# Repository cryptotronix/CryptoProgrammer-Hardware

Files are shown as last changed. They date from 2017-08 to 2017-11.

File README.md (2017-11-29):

# Crypto Programmer Hardware

This repo is the hardware files for the Crypto Programmer, a tool that
is hopefully useful for working with the Microchip
CryptoAuthentication Line.

Microchip already makes a useful development git
(https://www.microchip.com/developmenttools/productdetails.aspx?partno=at88ck101sk-mah-xpro),
and the schematics and firmware, but we wanted to "Build our own
Birdfeeder." The intention for this project is to fully Open Source
Hardware, although it doesn't quite meet the definition:
https://www.oshwa.org/definition/

## Overview

The intention of this tool is to expose a scripting-like interface on
a USB-Host that can send the raw byte commands to the part over
I2C. In other words, it is an USB-to-I2C bridge. Most dedicated
USB-to-I2C bridge have a hard-stop of a reasonable number of
bytes. The CryptoAuthentication parts however, send commands in the
few hundred bytes in a continuous I2C frame. Hence, why this tool
exists.

The other use-case for this tool is that you could program the MCU and
then use it to program other CryptoAuthentication parts with the use
of the "extra special button." I often lift CryptoAuthentication parts
from PCBs, drop them in a socket and dump their memory and this tool
should make that easier for me as well.

## Hardware Required

You'll want to attach the USB micro cable to the Crypto Programmer
then attach the plug-side to an appropriate port. I2C lines are on the
right-angle header and you can fly-wire to your heart's content, but
your life will be much easier if you get yourself the AT88CK101 Kit
(https://www.microchip.com/developmenttools/productdetails.aspx?partno=at88ck101sk-mah-xpro)
which comes with a UDFN or SOIC8 socket. The right angle header will
mate with the socket board. This will allow you to test your code
against the Microchip tools, use the CryptoProgammer, and then attach
it to a Microchip development board like a SAMV71.

## Status

Rev A of the Hardware is done and works (we think). We are still
working on the firmware, so once that's in a workable state that will
be released under a BSD license.

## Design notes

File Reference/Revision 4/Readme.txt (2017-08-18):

Filelist:
SAML21_Xplained_Pro_layer_plots_release_rev4.pdf : PCB Layer Plots
SAML21_Xplained_Pro_design_documentation_release_rev4.pdf : Design Documentation
SAML21_Xplained_Pro_PCB_stackup_rev4.pdf : PCB stackup used in the design.
BOM\Bill of Materials Print- SAML21_Xplained_Pro_release_rev4.xls : BOM, fitted components
CAD Source\* : Altium project source files
ExportSTEP\SAML21_Xplained_Pro_release_rev4.step : 3D Model of PCBA
Gerber\SAML21_Xplained_Pro_release_rev4.GP1 : Gerber files for GND
Gerber\SAML21_Xplained_Pro_release_rev4.GP2 : Gerber files for POWER
Gerber\SAML21_Xplained_Pro_release_rev4.GM1 : Gerber files for Mechanical 1
Gerber\SAML21_Xplained_Pro_release_rev4.GBO : Gerber files for Bottom Overlay
Gerber\SAML21_Xplained_Pro_release_rev4.GBL : Gerber files for Bottom Layer LF-signals
Gerber\SAML21_Xplained_Pro_release_rev4.GBS : Gerber files for Bottom Solder
Gerber\SAML21_Xplained_Pro_release_rev4.GBP : Gerber files for Bottom Paste
Gerber\SAML21_Xplained_Pro_release_rev4.GTL : Gerber files for Top Layer LF-signals
Gerber\SAML21_Xplained_Pro_release_rev4.GTO : Gerber files for Top Overlay
Gerber\SAML21_Xplained_Pro_release_rev4.GTP : Gerber files for Top Paste
Gerber\SAML21_Xplained_Pro_release_rev4.GTS : Gerber files for Top Solder
NC Drill\SAML21_Xplained_Pro_release_rev4.drl : Drill files, gerber
NC Drill\SAML21_Xplained_Pro_release_rev4.drr : Drill Files Report
ODB\SAML21_Xplained_Pro_release_rev4.zip : ODB++ Files
Pick Place\Pick Place for SAML21_Xplained_Pro_release_rev4.txt : Pick and Place file, component placement
Test Points\Assembly Testpoint Report for SAML21_Xplained_Pro_release_rev4.txt : Assembly Testpoint report, txt
Test Points\Assembly Testpoint Report for SAML21_Xplained_Pro_release_rev4.csv : Assembly Testpoint report, csv
NC Drill\SAML21_Xplained_Pro_release_rev4.LDP : Layer Pairs Definition
NC Drill\SAML21_Xplained_Pro_-SlotHoles_release_rev4.txt : Drill files, ASCII-SlotHoles
NC Drill\SAML21_Xplained_Pro_-RoundHoles_release_rev4.txt : Drill files, ASCII-RoundHoles

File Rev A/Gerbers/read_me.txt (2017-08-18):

Simply Works Electronics, LLC
Kirill V. Belyayev
kirill@kbelyayev.com
Crypto Programmer PCB, Rev A
08/11/2017

Files included:
	gerbers.zip		A zip file of all PCB gerbers

PCB Fab Requirements:
	- 2-Layer PCB Stackup
	- 1oz Top and Bottom Copper Thickness
	- Finish: Lead Free HASL
	- Soldermask on top and bottom
	- Silkscreen on top and bottom
	- PCB Thickness: 0.062"
	- PCB Material: FR-04

Gerber File Naming Conventions
	crypto_programmer.toplayer.ger		Top Copper
	crypto_programmer.tpaste.ger		Top Paste
	crypto_programmer.topsilkscreeen.ger	Top Silkscreen
	crypto_programmer.topsoldermask.ger	Top Soldermask
	crypto_programmer.bottomlayer.ger	Bottom Copper
	crypto_programmer.bpaste.ger		Bottom Paste
	crypto_programmer.bottomsilkscreeen.ger	Bottom Silkscreen
	crypto_programmer.bottomsoldermask.ger	Bottom Soldermask
	crypto_programmer.boardoutline.ger	PCB Outline
	crypto_programmer.drills.xln		Drill File, Excellon 24 format

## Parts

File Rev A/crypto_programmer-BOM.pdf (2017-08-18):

8/18/2017 | crypto_programmer-BOM.html
file:///mnt/Windows/Users/Kirill/Documents/GitHub/Crypto-Programmer/Rev%20A/crypto_programmer-BOM.html | 1/2

Partlist exported from /home/kirill/GitHub/Crypto-Programmer/Rev A/crypto_programmer.sch at 8/18/17 10:07 AM

Qty Value | Device | Package | Parts Description | MAN-
PART_NUM | MANUFACTURER VALUE
1 | 1.0K | R-US_R0603 | R0603 | R6 | RESISTOR, American symbol
3 | 1.0uF | C-EUC0603 | C0603 | C6, C14, C15 | CAPACITOR, European symbol
2 | 10.0K | R-US_R0603 | R0603 | R5, R8 RESISTOR, American
| | | | | symbol
5 | 100nF | C-EUC0603 | C0603 | C1, C5, C9, C11, C13 | CAPACITOR, European symbol
1 | 10104111-0001LF 10104111-0001LF 10104111-
| | | 0001LF | J1 | USB - micro AB USB 2.0
Receptacle Connector | 10104111-0001LF Amphenol
2 | 10uF | C-EUC0805 | C0805 | C10, C12 | CAPACITOR, European symbol
2 | 150 | R-US_R0603 | R0603 | R3, R4 RESISTOR, American
| | | | | symbol
2 | 1825910-6 | SWITCH-TACT- TH | SWITCH-TACT-
TH | S1, S2 Standard Tactile Switch
SPST-NO Top Actuated 1825910-6 | TE Connectivity
1 | 330 | R-US_R0603 | R0603 | R7 | RESISTOR, American
| | | | | symbol
2 | 4.75K | R-US_R0603 | R0603 | R1, R2 RESISTOR, American
| | | | | symbol
1 | ATSAML21E18B-
| AU | ATSAML21E18B-
| | AU | ATSAML21E18-
| | | AU | U1 | ARM® Cortex®-M0+
| | | | | SAM L21E
| | | | | Microcontroller IC 32-Bit
| | | | | 48MHz 256KB (256K x
8) FLASH

ATSAML21E18B-
AUT | Atmel
1 | BLM18PG471SN1D L0603 | L0603 | L1 | Various Inductors
1 | DNP | ABL-8.000MHZ-
| | B2 | ABL-
8.000MHZ-B2 X1 | 8MHz ±20ppm Crystal | ABL-8.000MHZ-
| | | | | | B2 | Abracon
1 | DNP | ABS07AIG- | ABS07AIG- | X2 | 32.768kHz ±20ppm | ABS07AIG- | Abracon

8/18/2017 | crypto_programmer-BOM.html
file:///mnt/Windows/Users/Kirill/Documents/GitHub/Crypto-Programmer/Rev%20A/crypto_programmer-BOM.html | 2/2
| | 32.768KHZ-9-T 32.768KHZ-9-T | | Crystal | 32.768KHZ-9-T
5 | DNP | C-EUC0603 | C0603
| | | C2, C3, C4, C7, C8 | CAPACITOR, European symbol
1 | DNP | L0603 | L0603 | L2 | Various Inductors
3 | DNP | M20-9990246 | M20-9990246 | J4, J5,
| | | J6 | 2 Positions Header | M20-9990246 | Harwin Inc.
1 | GREEN | LTST-C190GKT 0603 | D1 | LED Indication | LTST-C190 | Lite-On Inc. | GREEN
1 | M20-9951045 | M20-9951045 | M20-9951045 | J2 | 20 Positions Header
1 | MCP1703AT- 3302E/CB | MCP1703AT- 3302E/CB MCP1703AT-
| | 3302E/CB | U2 | Linear Voltage Regulator IC | MCP1703AT- 3302E/CB | Microchip Technology
1 | RED | LTST-C190EKT 0603 | D2 | LED Indication | LTST-C190 | Lite-On Inc. | RED
1 | TC2050-IDC-NLFP TC2050-IDC-
| | NLFP TC2050-IDC-
NLFP | J3 | JTAG Cable | TC2050-IDC-
NLFP | Tag Connect

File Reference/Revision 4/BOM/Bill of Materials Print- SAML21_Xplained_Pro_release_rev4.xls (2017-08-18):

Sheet: Part List Report
 | Component list |  | Top Level Schematics
 | Source Data From: |  | SAML21_Xplained_Pro.PrjPCB
 | Project: |  | SAML21_Xplained_Pro.PrjPCB
 | Variant: |  | Default_assembly
 | Report Date: | 13.07.2015 | 13:41:57
 | Print Date: | <Parameter CurrentDate not found> | <Parameter CurrentTime not found>
Fitted | Designator | Quantity | Value | Manufacturer | MPN | Description
Fitted | BT300 | 1 | CR1220 | Panasonic | CR1220 | CR1220 Lithium coin-cell battery
Fitted | C100, C101, C104, C305, C309, C311, C701, C703 | 8 | 4.7uF | tdk | C1608X5R1A475K | Ceramic capacitor, SMD 0603, X5R, 10V, 10% (de31036)
Fitted | C102, C103, C304, C307, C308, C310, C312, C600, C602, C604, C607 | 11 | 100n | Kemet | C0402C104K4RACTU | Ceramic capacitor, SMD 0402, X7R, 16V, +/-10%
Fitted | C105, C107 | 2 | 22u/10V | tdk | C2012X5R1A226M/0.85 | Ceramic capacitor, SMD 0805, X5R, 10V, Â±20%
Fitted | C106 | 1 | 10n |  |  | Ceramic capacitor, SMD 0402, X7R, 25V, +/-10%
Fitted | C301, C302 | 2 | 6.8p |  |  | Ceramic capacitor, SMD 0402, NP0, 50V, +/-5%
Fitted | C303 | 1 | 4.7n |  |  | Ceramic capacitor, SMD 0402, X7R, 25V, +/-10% (de35287)
Fitted | C306 | 1 | 1u | Kemet | C0402C105K9PAC | Ceramic capacitor, SMD 0402, X5R, 6.3V, +/-10% (de26942)
Fitted | C400, C401 | 2 | 22p |  |  | Ceramic capacitor, SMD 0402, NP0, 50V, +/-5%
Fitted | C402 | 1 | 10p |  |  | Ceramic capacitor, SMD 0402, NP0, 50V, +/-5%
Fitted | C404, C410, C411, C412, C413 | 5 | 100n | Kemet | C0402C104K4RACTU | Ceramic capacitor, SMD 0402, X7R, 16V, +/-10%
Fitted | C405, C409, C414, C415 | 4 | 2.2uF | Kemet | C0402C225M9PAC | Ceramic capacitor, SMD 0402, X5R, 6.3V, +/-20%
Fitted | C406, C407, C408 | 3 | 1 nF C0G | Murata | GRM1555C1H102JA01D | Ceramic capacitor, SMD 0402, C0G, 50V, +/-5%
Fitted | C601, C603 | 2 | 1uF | Murata | GRM188R61E105K | Ceramic capacitor, SMD 0603, X5R, 25V, ±10%
Fitted | C605 | 1 | 33n | Murata | GRM155R71E333KA88D | Ceramic capacitor, SMD 0402, X7R, 25V, ±10%
Fitted | C606 | 1 | 1n |  |  | Ceramic capacitor, SMD 0402, X7R, 50V, +/-10%
Fitted | C700, C704 | 2 | 100nF |  |  | Ceramic capacitor, SMD 0402, High Density Footprint
Fitted | C702, C706 | 2 | 150p |  |  | Ceramic capacitor, SMD 0402, X7R, 50V, +/-10%
Fitted | D200, D402 | 2 | PRTR5V0U2X | Philips | PRTR5V0U2X | Double rail-to-rail USB ESD protection diode
Fitted | D301, D401 | 2 | EL17-21UYC/A2 | Everlight | 17-21UYC/S530-A3/TR8 | LED, Yellow, Wave length=591nm, SMD 0805, ±70°
Fitted | D400 | 1 | EL17-21SYGC | Everlight | EL17-21SYGC | LED, Green, Wave length=575nm, SMD 0805, ±70°
Fitted | E1, E2, E3, E4 | 4 | SJ-5076 | 3M | SJ-5076 | 2.8mm adhesive feet,diam 8.0mm
Fitted | FIXTURE1 | 1 | Xplained PRO MCU board Jupiter Test Fixture | ESCATEC | Xplained PRO MCU board Jupiter Test Fixture | Xplained PRO MCU board Jupiter Test Fixture
Fitted | FW1 | 1 | EDBG secured firmware | ATMEL |  | EDBG secured firmware
Fitted | J101, J102, J301 | 3 | HMTSW-103-23-F-S-237 | SAMTEC | HMTSW-103-23-F-S-237 | 1x3 pin header, 2.54mm pitch, Pin-in-Paste THM, 1mm hole
Fitted | J103 | 1 | Pin header 1x2 right angle | Pro-data International Corp | 2213R-2G | 1x2 pin header, right angle, 2.54 mm pitch, through-hole
Fitted | J200, J201, J203 | 3 | P101-2*10RGF-139-ND |  | P101-2*10RGF-139-ND | Pin header, 2x10, Right Angle, 2.54mm, THM, Pin In Paste
Fitted | J202 | 1 | P101-2*02RGF-139-ND |  | P101-2*02RGF-139-ND | Pin header, 2x2, Right Angle, 2.54mm, THT, Pin In Paste
Fitted | J204, J400 | 2 | ZX62D-AB-5P8 |  |  | Micro USB AB Connector, Standard SMT + DIP
Fitted | J205 | 1 | PIN HEADER 2x5 | Garry | STL21-0730 G TT-10U | 2x5 pin header, 1.27mm pitch, THM
Fitted | J303 | 1 | 3000TR | Keystone Corp. | 3000TR | CR1220 Li-Ion coin-cell battery clip, SMD
Fitted | J304 | 1 | HMTSW-102-23-F-S-237 | SAMTEC | HMTSW-102-23-F-S-237 | 1x2 pin header, 2.54mm pitch, Pin-in-Paste THM
Fitted | JS100, JS101, JS102, JS301, JS302 | 5 | SNT-100-BK-G | SAMTEC | SNT-100-BK-G | Jumper cap for 2.54mm pinheader
Fitted | L300 | 1 | LQH3NPN100MJ0 | Murata | LQH3NPN100MJ0 | 10uH power inductor, Isat = 560mA , Itemp = 710mA, Rdc = 0.360ohm
Fitted | L301, L401, L402, L600 | 4 | BLM18PG471SN1 | Murata | BLM18PG471SN1 | SMD RF inductor 0603. Z=470Ohm (@100MHz), Max R(dc)=0.65Ohm, Max current=1A
Fitted | L700, L701 | 2 | BLM15BB221SN1 | Murata | BLM15BB221SN1 | SMD RF inductor 0402. Z=220Ohm (@100MHz), Max R(dc)=0.80Ohm, Max current=200mA
Fitted | LABEL1 | 1 | Label PCBA | ACT Logimark AS | 505462 | PCBA identification label PP Top White Gloss
Fitted | PCB1 | 1 | SAM L21 Xplained Pro PCB |  |  | SAM L21 Xplained Pro PCB, 4 layer, 60mm x 100mm
Fitted | PCBADOC1 | 1 | A09-2241 PCBA Files |  |  | SAM L21 Xplained Pro PCBA documentation
Fitted | Q100, Q101 | 2 | IRLML6402PBF | International Rectifier | IRLML6402PBF | P-ch. MOSFET. -30V, -3.7A continuous,RDS(ON)=0.05Ohm@VGS=-4,5V, RDS(ON)=0.08Ohm@VGS=-2.5V
Fitted | Q102 | 1 | 2N7002,215 | NXP | 2N7002,215 | N-Channel MOSFET. 60V, 0.300A continuous, 1.2A Peak. RDS(ON) = 3.8Ohm@VGS=4.5V, VGS(th)<2.5V
Fitted | Q400 | 1 | 2N7002DW | Fairchild | 2N7002DW | Dual N-Channel MOSFET, 60V, 115mA cont,RDS(ON) < 7.5 Ohm @50mA@5V, SOT-363
Fitted | Q500 | 1 | PMV48XP | NXP | PMV48XP,215 | P-Channel Digital FET. -30V, -3.5A continuous, -14A Peak. RDS(ON)=48mOhm@VGS=-4.5V, RDS(ON)=71mOhm@VGS=-2.5V. VGS(th)<1.25V
Fitted | Q501, Q701 | 2 | BSS138N | Infineon | BSS138N | Low leakage N-Channel MOSFET. 60V, 0.23A continuous, 0.92A Peak. RDS(ON) = 3.5Ohm@VGS=4.5V, VGS(th)<1.4V
Fitted | Q502, Q800, Q801, Q802 | 4 | BSH201 | NXP | BSH201,215 | P-Channel Digital FET. -60V, -0.3A continuous, -1.2A Peak. RDS(ON)=2.5@VGS=-10V, RDS(ON)=<5 ohm @VGS=-2.5V. VGS(th)<1.9V
Fitted | Q700 | 1 | IRLML6402 | International Rectifier | IRLML6402PBF | P-ch. MOSFET. -30V, -3.7A continuous,RDS(ON)=0.05Ohm@VGS=-4,5V, RDS(ON)=0.08Ohm@VGS=-2.5V
Fitted | R100, R103, R104, R410, R413 | 5 | 1M |  |  | Thick film resistor, SMD 0402, 1/16W, 1%
Fitted | R101, R107, R108, R304, R500, R501, R701, R800, R801, R802 | 10 | 100k |  |  | Thick film resistor, SMD 0402, 1/16W, 1%
Fitted | R102, R606 | 2 | 39k |  |  | Thick film resistor, SMD 0402, 1/16W, 1%
Fitted | R105 | 1 | 390R |  |  | Thick film resistor, SMD 0402, 1/16W, 1%
Fitted | R106, R109, R110, R201, R805 | 5 | 47k |  |  | Thick film resistor, SMD 0402, 1/16W, 1%
Fitted | R200 | 1 | 30k |  |  | Thick film resistor, SMD 0402, 1/16W, 1%
Fitted | R203, R303, R411, R412 | 4 | 330R |  |  | Thick film resistor, SMD 0402, 1/16W, 1%
Fitted | R300, R305, R311, R421, R422, R803 | 6 | 39R |  |  | Thick film resistor, SMD 0402, 1/16W, 1%
Fitted | R301, R307, R600, R601, R706 | 5 | 0R | (n/a) | RMCF0402ZT0R00 | RES 0.0 OHM 1/16W 0402 SMD
Fitted | R302, R703, R708, R709 | 4 | 10k | vishay | CRCW040210K0FKED | Thick film resistor, SMD 0402, 1/16W, 1%
Fitted | R306, R310, R602, R603 | 4 | 4.7k |  |  | Thick film resistor, SMD 0402, 1/16W, 1%
Fitted | R401, R402, R409 | 3 | 1k |  |  | Thick film resistor, SMD 0402, 1/16W, 1%
Fitted | R414, R416, R417, R418, R419, R420 | 6 | 330R |  |  | Thick film resistor, SMD 0402, 1/16W, 1%
Fitted | R423 | 1 | 6.81k |  |  | Thick film resistor, SMD 0402, 1/16W, 1%
Fitted | R604 | 1 | 2k |  |  | Thick film resistor, SMD 0402, 1/16W, 1%
Fitted | R605 | 1 | 33k |  |  | Thick film resistor, SMD 0402, 1/16W, 1%
Fitted | R700 | 1 | 0.1R | vishay | WSL0603R1000FEA | WSL0603R1000FEA, metal strip resistor, 0.1 Ohm, +-1%, 0603 SMD, 1/10 W, TEMPCO +-75 ppm/Â°C
Fitted | R702, R704 | 2 | 100R | Panasonic | ERA3YEB101V | ERA-3YEB101V, metal film, 100R Â±0.1%, resistor in 0603 at 100mW, TEMPCO Â±25ppm/Â°C, Max V=75V
Fitted | R705 | 1 | 680R |  |  | Thick film resistor, SMD 0402, 1/16W, 1%
Fitted | R707 | 1 | 2k |  |  | Thick film resistor, SMD 0603, 1/10W, 1%
Fitted | R804 | 1 | 2.2k |  |  | Thick film resistor, SMD 0402, 1/16W, 1%
Fitted | R806 | 1 | 4.7M |  |  | Thick film SMD 0402 1/16W 1%
Fitted | SW300, SW301 | 2 | SKRAAKE010 | ALPS | SKRAAKE010 | 6.2x6.2 mm SMD tact switch, same as A08-0091 but less force is needed
Fitted | TEST1 | 1 | SAM L21 Xplained Pro Test |  |  | Fixture eggTest for SAM L21 Xplained Pro
Fitted | TESTDOC1 | 1 | SAM L21 Xplained Pro Test Instructions |  |  | SAM L21 Xplained Pro Test Instructions
Fitted | U100 | 1 | TLV70033DSE | Texas Instruments | TLV70033DSE | LDO, 200 mA, Iq=31 uA, Vdo=250mV, Vout=3.3V, VIN= 2 V to 5.5V, SON-6 package
Fitted | U101 | 1 | TPS2113PWR | Texas Instruments | TPS2113PWR | Autoswitching 2:1 Power Mux
Fitted | U102 | 1 | STMPS2161STR |  |  | Single channel power switch, 1A, reverse block, active low enabled.
Fitted | U103 | 1 | TPS73533DRV | Texas Instruments | TPS73533DRV | Low noise LDO, 500 mA, Vout=3.3V, 2% accuracy, IQ=46uA, noise=28uVrms, VIN= 2.7V to 6.5V, Vdo=280mV,stable with low ESR capacitor
Fitted | U300 | 1 | ATSAML21J18B-AUT |  |  | Atmel 32-bit RISC MCU 64pin
Fitted | U400 | 1 | AT32UC3A4256J-C1UR | ATMEL | AT32UC3A4256J-C1UR | AVR 32-bit RISC MCU
Fitted | U600 | 1 | SAMD20E17A-AUT | ATMEL | ATSAMD20E17A-AUT | Atmel 32bit RISC MCU 32 pin
Fitted | U601 | 1 | LM4041CEM3-ADJ | National Semiconductor | LM4041CEM3-ADJ | Adjustable shunt voltage regulator, 1.24 to 10V out
Fitted | U700 | 1 | AD8656 | Analog Devices | AD8656ARMZ | AD8656, dual low noise precision OpAmp, rail-to-rail, low offset 250uV, GBP 28 MHz, 8MSOP
Fitted | U701 | 1 | ADA4528-1 | Analog Devices | ADA4528-1ARMZ | Precision OpAmp, Zero-Drift 0.015uV/K, ultra low noise 5.6nV/sqrt(Hz), Vo=2uV, GBW=4MHz, single supply 2.2V to 5.5V or dual supply +-1V to +-2.75V, rail to rail, unity gain stable
Fitted | XC300 | 1 | 32.768kHz +/-20PPM 7pF SMD | Micro Crystal | MS1V-T1K 32.768kHz 7pF +/-20PPM TA | 32k768 crystal, +-20ppm, CL=7pF, max ESR 60kOhm, SMD
Fitted | XC400 | 1 | 12.0MHz | Fox Electronics | FQ5032B-12-C-C-C-200-1 | Fox FQ5032B 12.0MHz SMD crystal 738B-12
Not Fitted | C200, C403 | 0 | 4.7n |  |  | Ceramic capacitor, SMD 0402, X7R, 25V, +/-10%
Not Fitted | C300, C313 | 0 | 22p |  |  | Ceramic capacitor, SMD 0402, NP0, 50V, +/-5%
Not Fitted | C705 | 0 | 1n |  |  | Ceramic capacitor, SMD 0402, X7R, 50V, +/-10%
Not Fitted | R202, R424 | 0 | 1M | KOA | RK73H1ETTP1004F | Thick film resistor, SMD 0402, 1/16W, 1%
Not Fitted | XC301 | 0 | 12.0MHz | Fox Electronics | FQ5032B-12-C-C-C-200-1 / 738B-12 | Fox FQ5032B 12.0MHz SMD crystal 738B-12
 |  | 183
Approved |  |  | Notes

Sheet: Project Information
Project Full Path | E:\svn\devkits\SAML21_Xplained_Pro\02_Documentation\Release_Files\Atmel-42405-SAML21-Xplained-Pro_User-Guide\Revision 4\CAD Source\SAML21_Xplained_Pro.PrjPCB
Project Filename | SAML21_Xplained_Pro.PrjPCB
Variant Name | Default_assembly
Data-Source Filename | SAML21_Xplained_Pro.PrjPCB
Data-Source Full Path | E:\svn\devkits\SAML21_Xplained_Pro\02_Documentation\Release_Files\Atmel-42405-SAML21-Xplained-Pro_User-Guide\Revision 4\CAD Source\SAML21_Xplained_Pro.PrjPCB
Title | Top Level Schematics
Total Quantity | 183
Report Time | 13:41:57
Report Date | 13.07.2015
Report Date & Tine | 13.07.2015 13:41:57
Output Name | Bill of Materials Fitted
Output Type | BOM_PartType
Output Generator Name | BOM
Output Generator Description | Bill of Materials

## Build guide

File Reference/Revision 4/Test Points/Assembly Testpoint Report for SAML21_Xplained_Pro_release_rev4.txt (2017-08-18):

Net         Name        X Coord     Y Coord     Side        Hole Size   Type        
TARGET_USB_SHIELDJ204-8       -46.209mm      -4.8mm  Bottom          0.65mm  Through hole
VCC_MCU_VDDIOJ304-2       -37.055mm    -66.55mm  Bottom             1mm  Through hole
VCC_EXT_P5V0J202-1         -6.97mm    -13.49mm  Bottom             1mm  Through hole
VCC_P5V0    J202-3         -6.97mm    -16.03mm  Bottom             1mm  Through hole
VCC_TARGET_P3V3J202-4         -4.43mm    -16.03mm  Bottom             1mm  Through hole
ID2         J201-1         -6.97mm    -64.29mm  Bottom             1mm  Through hole
PA18_S1_UART_TXJ201-14        -4.43mm    -79.53mm  Bottom             1mm  Through hole
PA19_S1_UART_RXJ201-13        -6.97mm    -79.53mm  Bottom             1mm  Through hole
EDBG_SPI_DGI_MOSIJ201-16        -4.43mm    -82.07mm  Bottom             1mm  Through hole
PA17_GPIO   J201-15        -6.97mm    -82.07mm  Bottom             1mm  Through hole
EDBG_SPI_DGI_SCKJ201-18        -4.43mm    -84.61mm  Bottom             1mm  Through hole
PB16_S5_SPI_MISOJ201-17        -6.97mm    -84.61mm  Bottom             1mm  Through hole
PB14_GPIO_IRQ14J201-9         -6.97mm    -74.45mm  Bottom             1mm  Through hole
PB12_PWM_TC4_0J201-7         -6.97mm    -71.91mm  Bottom             1mm  Through hole
PB13_PWM_TC4_1J201-8         -4.43mm    -71.91mm  Bottom             1mm  Through hole
PA20_GPIO   J201-5         -6.97mm    -69.37mm  Bottom             1mm  Through hole
PA21_GPIO   J201-6         -4.43mm    -69.37mm  Bottom             1mm  Through hole
PA10_ADC18_PTCY8J201-3         -6.97mm    -66.83mm  Bottom             1mm  Through hole
PA11_ADC19  J201-4         -4.43mm    -66.83mm  Bottom             1mm  Through hole
PB15_GPIO_SSJ201-10        -4.43mm    -74.45mm  Bottom             1mm  Through hole
NetJ102_2   J103-2        -38.73mm    -10.95mm  Bottom             1mm  Through hole
VCC_MCU_P3V3J103-1        -41.27mm    -10.95mm  Bottom             1mm  Through hole
TARGET_RESETJ205-10        -8.24mm    -23.01mm  Bottom          0.65mm  Through hole
SWDIO       J205-2         -3.16mm    -23.01mm  Bottom          0.65mm  Through hole
SWDCLK      J205-4         -4.43mm    -23.01mm  Bottom          0.65mm  Through hole
ID1         J200-1         -6.97mm    -28.73mm  Bottom             1mm  Through hole
EDBG_DGI_SDAJ200-11        -6.97mm    -41.43mm  Bottom             1mm  Through hole
EDBG_DGI_SCLJ200-12        -4.43mm    -41.43mm  Bottom             1mm  Through hole
PB08_S4_UART_TXJ200-14        -4.43mm    -43.97mm  Bottom             1mm  Through hole
PB09_S4_UART_RXJ200-13        -6.97mm    -43.97mm  Bottom             1mm  Through hole
PA06_S0_SPI_MOSIJ200-16        -4.43mm    -46.51mm  Bottom             1mm  Through hole
PA05_S0_SPI_SSJ200-15        -6.97mm    -46.51mm  Bottom             1mm  Through hole
PA07_S0_SPI_SCKJ200-18        -4.43mm    -49.05mm  Bottom             1mm  Through hole
PA04_S0_SPI_MISOJ200-17        -6.97mm    -49.05mm  Bottom             1mm  Through hole
PB04_GPIO_IRQ4J200-9         -6.97mm    -38.89mm  Bottom             1mm  Through hole
PA12_PWM_TCC2_0J200-7         -6.97mm    -36.35mm  Bottom             1mm  Through hole
PA13_PWM_TCC2_1J200-8         -4.43mm    -36.35mm  Bottom             1mm  Through hole
PB06_GPIO   J200-5         -6.97mm    -33.81mm  Bottom             1mm  Through hole
PB07_GPIO   J200-6         -4.43mm    -33.81mm  Bottom             1mm  Through hole
PB05_ADC13  J200-3         -6.97mm    -31.27mm  Bottom             1mm  Through hole
PA03_ADC1   J200-4         -4.43mm    -31.27mm  Bottom             1mm  Through hole
PA02_GPIO_SS_BTNJ200-10        -4.43mm    -38.89mm  Bottom             1mm  Through hole
SHIELD      J400-9       -17.825mm      -4.8mm  Bottom          0.65mm  Through hole
PA27_GPIO_SSJ203-10       -28.73mm    -95.57mm  Bottom             1mm  Through hole
PB01_ADC9   J203-4        -21.11mm    -95.57mm  Bottom             1mm  Through hole
PB00_ADC8   J203-3        -21.11mm    -93.03mm  Bottom             1mm  Through hole
PA15_GPIO   J203-6        -23.65mm    -95.57mm  Bottom             1mm  Through hole
PB30_GPIO   J203-5        -23.65mm    -93.03mm  Bottom             1mm  Through hole
PB11_PWM_TCC0_5J203-8        -26.19mm    -95.57mm  Bottom             1mm  Through hole
PB10_PWM_TCC0_4J203-7        -26.19mm    -93.03mm  Bottom             1mm  Through hole
PA16_GPIO_IRQJ203-9        -28.73mm    -93.03mm  Bottom             1mm  Through hole
PB17_S5_SPI_SSJ203-15       -36.35mm    -93.03mm  Bottom             1mm  Through hole
ID3         J203-1        -18.57mm    -93.03mm  Bottom             1mm  Through hole
PB02_USB_ID Free-0       -33.495mm   -47.125mm  Bottom          0.65mm  Through hole
EDBG_SPI_DGI_SSFree-0       -32.225mm   -47.125mm  Bottom          0.65mm  Through hole
PA14_USB_VBUSFree-0       -36.035mm   -47.125mm  Bottom          0.65mm  Through hole
PA23_S3_UART_RXFree-0        -25.85mm   -37.275mm  Bottom          0.65mm  Through hole
EDBG_CDC_USART_RXFree-0        -27.12mm   -37.275mm  Bottom          0.65mm  Through hole
PB03_VBAT   J301-2      -47.1564mm   -51.861mm  Bottom             1mm  Through hole
VCC_BATT    J301-1      -47.1564mm   -49.321mm  Bottom             1mm  Through hole
NetJ101_3   J102-3       -41.776mm    -14.76mm  Bottom             1mm  Through hole
VCC_P3V3_CM_INJ102-1       -41.776mm    -19.84mm  Bottom             1mm  Through hole
NetR300_1   TP300-1          -33mm      -1.5mm  Bottom             0mm  Surface mount
VCC_CM_P3V3 TP407-1        -38.6mm      -7.5mm  Bottom             0mm  Surface mount
VCC_P3V3    J100-2         -27.9mm    -12.15mm  Bottom             0mm  Surface mount
NetR311_1   TP301-1          -26mm      -1.5mm  Bottom             0mm  Surface mount
GND         TP400-1        -41.6mm      -1.5mm  Bottom             0mm  Surface mount
EDBG_FORCE_BOOTTP401-1        -38.6mm      -1.5mm  Bottom             0mm  Surface mount
EDBG_JTAG_TCKTP402-1        -41.6mm      -3.5mm  Bottom             0mm  Surface mount
EDBG_JTAG_TDITP403-1        -41.6mm      -5.5mm  Bottom             0mm  Surface mount
EDBG_JTAG_TDOTP404-1        -38.6mm      -5.5mm  Bottom             0mm  Surface mount
EDBG_JTAG_TMSTP405-1        -41.6mm      -7.5mm  Bottom             0mm  Surface mount
EDBG_RESET_NTP406-1        -38.6mm      -3.5mm  Bottom             0mm  Surface mount
PA31_SWDIO  Free-3        -24.05mm  -40.0875mm  Bottom             0mm  Surface mount
PA30_SWDCLK Free-3       -23.175mm   -41.275mm  Bottom             0mm  Surface mount
NetQ700_2   Free-3        -46.85mm     -15.4mm  Bottom             0mm  Surface mount
CM_PA27_EXTINT15Free-3         -40.1mm   -28.875mm  Bottom             0mm  Surface mount
CM_PA28_EXTINT8Free-3         -40.1mm    -30.15mm  Bottom             0mm  Surface mount
NetC106_2   Free-3        -30.15mm     -7.75mm  Bottom             0mm  Surface mount
VCC_PRE_AMP_P5V0Free-3       -58.075mm    -17.65mm  Bottom             0mm  Surface mount
EDBG_SPI_DGI_MISOFree-3       -30.775mm   -26.175mm  Bottom             0mm  Surface mount
NetC706_1   Free-3       -57.425mm   -23.575mm  Bottom             0mm  Surface mount
VREF_FB     Free-3       -44.735mm     -42.8mm  Bottom             0mm  Surface mount
CM_PA15_GPIOFree-3      -50.6488mm  -28.3738mm  Bottom             0mm  Surface mount
NetQ701_3   Free-3        -51.45mm     -20.8mm  Bottom             0mm  Surface mount
VCC_CM_VDDANAFree-3         -53.7mm    -37.15mm  Bottom             0mm  Surface mount
CM_PA03_VREFAFree-3       -48.875mm    -40.45mm  Bottom             0mm  Surface mount
VCC_CM_CORE Free-3       -37.925mm     -33.1mm  Bottom             0mm  Surface mount
VCC_FILTER_P3V3Free-3       -52.625mm   -21.725mm  Bottom             0mm  Surface mount
NetC705_2   Free-3       -58.525mm    -26.95mm  Bottom             0mm  Surface mount
CM_PA08_AIN16Free-3       -52.975mm     -30.9mm  Bottom             0mm  Surface mount
NetC702_1   Free-3       -54.925mm     -32.7mm  Bottom             0mm  Surface mount
NetQ102_1   Free-3      -10.4822mm  -17.3834mm  Bottom             0mm  Surface mount
NetR100_1   Free-3       -19.825mm        -4mm  Bottom             0mm  Surface mount
VCC_EDBG_USB_P5V0Free-3        -19.85mm     -5.55mm  Bottom             0mm  Surface mount
NetQ101_1   Free-3         -15.9mm   -13.775mm  Bottom             0mm  Surface mount
NetQ500_2   Free-3       -48.125mm   -15.425mm  Bottom             0mm  Surface mount
NetQ701_1   Free-3         -52.6mm     -19.3mm  Bottom             0mm  Surface mount
NetQ701_2   Free-3       -58.225mm   -21.125mm  Bottom             0mm  Surface mount
NetQ501_3   Free-3        -50.75mm    -11.85mm  Bottom             0mm  Surface mount
NetC402_1   Free-3         -18.9mm    -19.65mm  Bottom             0mm  Surface mount
NetC405_1   Free-3       -25.575mm     -14.1mm  Bottom             0mm  Surface mount
NetQ400_6   Free-3          -4.1mm   -12.025mm  Bottom             0mm  Surface mount
NetQ400_3   Free-3        -2.575mm     -6.55mm  Bottom             0mm  Surface mount
NetR107_2   Free-3       -21.175mm    -14.55mm  Bottom             0mm  Surface mount
NetQ800_3   Free-3       -43.225mm   -22.875mm  Bottom             0mm  Surface mount
NetQ801_3   Free-3       -46.775mm   -22.875mm  Bottom             0mm  Surface mount
NetQ802_3   Free-3       -50.325mm   -22.875mm  Bottom             0mm  Surface mount
NetR105_2   Free-3        -14.15mm    -8.975mm  Bottom             0mm  Surface mount
CM_PA01_GPIOVia          -40.175mm   -26.675mm  Bottom          0.25mm  Through hole
CM_PA00_GPIOVia          -43.725mm   -26.675mm  Bottom          0.25mm  Through hole
CM_PA17_SERCOM1_SCLVia          -36.275mm    -24.95mm  Bottom          0.25mm  Through hole
CM_PA16_SERCOM1_SDAVia           -36.95mm   -23.775mm  Bottom          0.25mm  Through hole
CM_PA24_SERCOM3_PAD2_SPI_MISOVia          -20.225mm     -32.7mm  Bottom          0.25mm  Through hole
CM_PA25_SPI_SSVia           -22.55mm     -31.6mm  Bottom          0.25mm  Through hole
CM_RESET_N  Via           -25.75mm   -32.175mm  Bottom          0.25mm  Through hole
CM_PA23_SERCOM3_PAD1_SPI_SCKVia          -22.125mm     -33.4mm  Bottom          0.25mm  Through hole
CM_PA22_SERCOM3_PAD0_SPI_MOSIVia           -20.35mm    -34.05mm  Bottom          0.25mm  Through hole
CM_PA14_GCLK0Via           -21.35mm    -35.05mm  Bottom          0.25mm  Through hole
CM_PA05_AIN5Via           -52.85mm   -28.725mm  Bottom          0.25mm  Through hole
CM_PA11_GCLK5Via          -29.625mm   -25.325mm  Bottom          0.25mm  Through hole
VCC_VSW     Via          -29.075mm   -49.725mm  Bottom          0.25mm  Through hole
VCC_MCU_VDDCOREVia           -27.35mm   -49.775mm  Bottom          0.25mm  Through hole
STATUS_LED_CTRLVia             -2.7mm    -12.25mm  Bottom          0.25mm  Through hole
TARGET_USB_IDVia          -32.275mm     -15.2mm  Bottom          0.25mm  Through hole
CM_PA31_SWDIOVia          -24.675mm   -35.675mm  Bottom          0.25mm  Through hole
CM_PA30_SWCLKVia            -25.9mm   -35.125mm  Bottom          0.25mm  Through hole
TARGET_MCU_RESETVia         -28.9125mm   -27.525mm  Bottom          0.25mm  Through hole
NetCS300_1  Via           -48.75mm   -80.075mm  Bottom          0.25mm  Through hole
VCC_MCU_VDDANAVia          -40.725mm    -57.95mm  Bottom          0.25mm  Through hole
INPUT_VOLTAGE_DETECTEDVia           -9.925mm      -9.2mm  Bottom          0.25mm  Through hole
VCC_TARGET_USB_P5V0Via          -22.525mm     -11.4mm  Bottom          0.25mm  Through hole
NetD301_2   Via          -36.625mm    -11.45mm  Bottom          0.25mm  Through hole
CM_PA10_GPIOVia            -52.7mm    -32.65mm  Bottom          0.25mm  Through hole
CM_PA18_CMP0Via            -44.2mm   -20.225mm  Bottom          0.25mm  Through hole
NetQ502_3   Via           -50.75mm     -14.3mm  Bottom          0.25mm  Through hole
DGI_GPIO3   Via            -15.6mm     -26.2mm  Bottom          0.25mm  Through hole
EDBG_CDC_USART_TXVia          -27.575mm   -26.175mm  Bottom          0.25mm  Through hole
DGI_GPIO2   Via          -16.875mm     -26.2mm  Bottom          0.25mm  Through hole
DGI_GPIO1   Via           -18.15mm     -26.2mm  Bottom          0.25mm  Through hole
DGI_GPIO0   Via          -19.425mm     -26.2mm  Bottom          0.25mm  Through hole
NetD401_1   Via             -1.3mm     -7.25mm  Bottom          0.25mm  Through hole
POWER_LED_CTRLVia            -6.35mm     -8.75mm  Bottom          0.25mm  Through hole
NetD400_1   Via            -6.35mm    -10.05mm  Bottom          0.25mm  Through hole
NetC404_1   Via           -29.85mm    -20.25mm  Bottom          0.25mm  Through hole
NetC407_1   Via          -13.275mm      -7.4mm  Bottom          0.25mm  Through hole
CM_PA09_AIN17Via           -38.75mm     -22.7mm  Bottom          0.25mm  Through hole

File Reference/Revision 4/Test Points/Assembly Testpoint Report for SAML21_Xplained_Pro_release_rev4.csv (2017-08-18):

Net | Name | X Coord | Y Coord | Side | Hole Size | Type
TARGET_USB_SHIELD | J204-8 | -46.209mm | -4.8mm | Bottom | 0.65mm | Through hole
VCC_MCU_VDDIO | J304-2 | -37.055mm | -66.55mm | Bottom | 1mm | Through hole
VCC_EXT_P5V0 | J202-1 | -6.97mm | -13.49mm | Bottom | 1mm | Through hole
VCC_P5V0 | J202-3 | -6.97mm | -16.03mm | Bottom | 1mm | Through hole
VCC_TARGET_P3V3 | J202-4 | -4.43mm | -16.03mm | Bottom | 1mm | Through hole
ID2 | J201-1 | -6.97mm | -64.29mm | Bottom | 1mm | Through hole
PA18_S1_UART_TX | J201-14 | -4.43mm | -79.53mm | Bottom | 1mm | Through hole
PA19_S1_UART_RX | J201-13 | -6.97mm | -79.53mm | Bottom | 1mm | Through hole
EDBG_SPI_DGI_MOSI | J201-16 | -4.43mm | -82.07mm | Bottom | 1mm | Through hole
PA17_GPIO | J201-15 | -6.97mm | -82.07mm | Bottom | 1mm | Through hole
EDBG_SPI_DGI_SCK | J201-18 | -4.43mm | -84.61mm | Bottom | 1mm | Through hole
PB16_S5_SPI_MISO | J201-17 | -6.97mm | -84.61mm | Bottom | 1mm | Through hole
PB14_GPIO_IRQ14 | J201-9 | -6.97mm | -74.45mm | Bottom | 1mm | Through hole
PB12_PWM_TC4_0 | J201-7 | -6.97mm | -71.91mm | Bottom | 1mm | Through hole
PB13_PWM_TC4_1 | J201-8 | -4.43mm | -71.91mm | Bottom | 1mm | Through hole
PA20_GPIO | J201-5 | -6.97mm | -69.37mm | Bottom | 1mm | Through hole
PA21_GPIO | J201-6 | -4.43mm | -69.37mm | Bottom | 1mm | Through hole
PA10_ADC18_PTCY8 | J201-3 | -6.97mm | -66.83mm | Bottom | 1mm | Through hole
PA11_ADC19 | J201-4 | -4.43mm | -66.83mm | Bottom | 1mm | Through hole
PB15_GPIO_SS | J201-10 | -4.43mm | -74.45mm | Bottom | 1mm | Through hole
NetJ102_2 | J103-2 | -38.73mm | -10.95mm | Bottom | 1mm | Through hole
VCC_MCU_P3V3 | J103-1 | -41.27mm | -10.95mm | Bottom | 1mm | Through hole
TARGET_RESET | J205-10 | -8.24mm | -23.01mm | Bottom | 0.65mm | Through hole
SWDIO | J205-2 | -3.16mm | -23.01mm | Bottom | 0.65mm | Through hole
SWDCLK | J205-4 | -4.43mm | -23.01mm | Bottom | 0.65mm | Through hole
ID1 | J200-1 | -6.97mm | -28.73mm | Bottom | 1mm | Through hole
EDBG_DGI_SDA | J200-11 | -6.97mm | -41.43mm | Bottom | 1mm | Through hole
EDBG_DGI_SCL | J200-12 | -4.43mm | -41.43mm | Bottom | 1mm | Through hole
PB08_S4_UART_TX | J200-14 | -4.43mm | -43.97mm | Bottom | 1mm | Through hole
PB09_S4_UART_RX | J200-13 | -6.97mm | -43.97mm | Bottom | 1mm | Through hole
PA06_S0_SPI_MOSI | J200-16 | -4.43mm | -46.51mm | Bottom | 1mm | Through hole
PA05_S0_SPI_SS | J200-15 | -6.97mm | -46.51mm | Bottom | 1mm | Through hole
PA07_S0_SPI_SCK | J200-18 | -4.43mm | -49.05mm | Bottom | 1mm | Through hole
PA04_S0_SPI_MISO | J200-17 | -6.97mm | -49.05mm | Bottom | 1mm | Through hole
PB04_GPIO_IRQ4 | J200-9 | -6.97mm | -38.89mm | Bottom | 1mm | Through hole
PA12_PWM_TCC2_0 | J200-7 | -6.97mm | -36.35mm | Bottom | 1mm | Through hole
PA13_PWM_TCC2_1 | J200-8 | -4.43mm | -36.35mm | Bottom | 1mm | Through hole
PB06_GPIO | J200-5 | -6.97mm | -33.81mm | Bottom | 1mm | Through hole
PB07_GPIO | J200-6 | -4.43mm | -33.81mm | Bottom | 1mm | Through hole
PB05_ADC13 | J200-3 | -6.97mm | -31.27mm | Bottom | 1mm | Through hole
PA03_ADC1 | J200-4 | -4.43mm | -31.27mm | Bottom | 1mm | Through hole
PA02_GPIO_SS_BTN | J200-10 | -4.43mm | -38.89mm | Bottom | 1mm | Through hole
SHIELD | J400-9 | -17.825mm | -4.8mm | Bottom | 0.65mm | Through hole
PA27_GPIO_SS | J203-10 | -28.73mm | -95.57mm | Bottom | 1mm | Through hole
PB01_ADC9 | J203-4 | -21.11mm | -95.57mm | Bottom | 1mm | Through hole
PB00_ADC8 | J203-3 | -21.11mm | -93.03mm | Bottom | 1mm | Through hole
PA15_GPIO | J203-6 | -23.65mm | -95.57mm | Bottom | 1mm | Through hole
PB30_GPIO | J203-5 | -23.65mm | -93.03mm | Bottom | 1mm | Through hole
PB11_PWM_TCC0_5 | J203-8 | -26.19mm | -95.57mm | Bottom | 1mm | Through hole
PB10_PWM_TCC0_4 | J203-7 | -26.19mm | -93.03mm | Bottom | 1mm | Through hole
PA16_GPIO_IRQ | J203-9 | -28.73mm | -93.03mm | Bottom | 1mm | Through hole
PB17_S5_SPI_SS | J203-15 | -36.35mm | -93.03mm | Bottom | 1mm | Through hole
ID3 | J203-1 | -18.57mm | -93.03mm | Bottom | 1mm | Through hole
PB02_USB_ID | Free-0 | -33.495mm | -47.125mm | Bottom | 0.65mm | Through hole
EDBG_SPI_DGI_SS | Free-0 | -32.225mm | -47.125mm | Bottom | 0.65mm | Through hole
PA14_USB_VBUS | Free-0 | -36.035mm | -47.125mm | Bottom | 0.65mm | Through hole
PA23_S3_UART_RX | Free-0 | -25.85mm | -37.275mm | Bottom | 0.65mm | Through hole
EDBG_CDC_USART_RX | Free-0 | -27.12mm | -37.275mm | Bottom | 0.65mm | Through hole
PB03_VBAT | J301-2 | -47.1564mm | -51.861mm | Bottom | 1mm | Through hole
VCC_BATT | J301-1 | -47.1564mm | -49.321mm | Bottom | 1mm | Through hole
NetJ101_3 | J102-3 | -41.776mm | -14.76mm | Bottom | 1mm | Through hole
VCC_P3V3_CM_IN | J102-1 | -41.776mm | -19.84mm | Bottom | 1mm | Through hole
NetR300_1 | TP300-1 | -33mm | -1.5mm | Bottom | 0mm | Surface mount
VCC_CM_P3V3 | TP407-1 | -38.6mm | -7.5mm | Bottom | 0mm | Surface mount
VCC_P3V3 | J100-2 | -27.9mm | -12.15mm | Bottom | 0mm | Surface mount
NetR311_1 | TP301-1 | -26mm | -1.5mm | Bottom | 0mm | Surface mount
GND | TP400-1 | -41.6mm | -1.5mm | Bottom | 0mm | Surface mount
EDBG_FORCE_BOOT | TP401-1 | -38.6mm | -1.5mm | Bottom | 0mm | Surface mount
EDBG_JTAG_TCK | TP402-1 | -41.6mm | -3.5mm | Bottom | 0mm | Surface mount
EDBG_JTAG_TDI | TP403-1 | -41.6mm | -5.5mm | Bottom | 0mm | Surface mount
EDBG_JTAG_TDO | TP404-1 | -38.6mm | -5.5mm | Bottom | 0mm | Surface mount
EDBG_JTAG_TMS | TP405-1 | -41.6mm | -7.5mm | Bottom | 0mm | Surface mount
EDBG_RESET_N | TP406-1 | -38.6mm | -3.5mm | Bottom | 0mm | Surface mount
PA31_SWDIO | Free-3 | -24.05mm | -40.0875mm | Bottom | 0mm | Surface mount
PA30_SWDCLK | Free-3 | -23.175mm | -41.275mm | Bottom | 0mm | Surface mount
NetQ700_2 | Free-3 | -46.85mm | -15.4mm | Bottom | 0mm | Surface mount
CM_PA27_EXTINT15 | Free-3 | -40.1mm | -28.875mm | Bottom | 0mm | Surface mount
CM_PA28_EXTINT8 | Free-3 | -40.1mm | -30.15mm | Bottom | 0mm | Surface mount
NetC106_2 | Free-3 | -30.15mm | -7.75mm | Bottom | 0mm | Surface mount
VCC_PRE_AMP_P5V0 | Free-3 | -58.075mm | -17.65mm | Bottom | 0mm | Surface mount
EDBG_SPI_DGI_MISO | Free-3 | -30.775mm | -26.175mm | Bottom | 0mm | Surface mount
NetC706_1 | Free-3 | -57.425mm | -23.575mm | Bottom | 0mm | Surface mount
VREF_FB | Free-3 | -44.735mm | -42.8mm | Bottom | 0mm | Surface mount
CM_PA15_GPIO | Free-3 | -50.6488mm | -28.3738mm | Bottom | 0mm | Surface mount
NetQ701_3 | Free-3 | -51.45mm | -20.8mm | Bottom | 0mm | Surface mount
VCC_CM_VDDANA | Free-3 | -53.7mm | -37.15mm | Bottom | 0mm | Surface mount
CM_PA03_VREFA | Free-3 | -48.875mm | -40.45mm | Bottom | 0mm | Surface mount
VCC_CM_CORE | Free-3 | -37.925mm | -33.1mm | Bottom | 0mm | Surface mount
VCC_FILTER_P3V3 | Free-3 | -52.625mm | -21.725mm | Bottom | 0mm | Surface mount
NetC705_2 | Free-3 | -58.525mm | -26.95mm | Bottom | 0mm | Surface mount
CM_PA08_AIN16 | Free-3 | -52.975mm | -30.9mm | Bottom | 0mm | Surface mount
NetC702_1 | Free-3 | -54.925mm | -32.7mm | Bottom | 0mm | Surface mount
NetQ102_1 | Free-3 | -10.4822mm | -17.3834mm | Bottom | 0mm | Surface mount
NetR100_1 | Free-3 | -19.825mm | -4mm | Bottom | 0mm | Surface mount
VCC_EDBG_USB_P5V0 | Free-3 | -19.85mm | -5.55mm | Bottom | 0mm | Surface mount
NetQ101_1 | Free-3 | -15.9mm | -13.775mm | Bottom | 0mm | Surface mount
NetQ500_2 | Free-3 | -48.125mm | -15.425mm | Bottom | 0mm | Surface mount
NetQ701_1 | Free-3 | -52.6mm | -19.3mm | Bottom | 0mm | Surface mount
NetQ701_2 | Free-3 | -58.225mm | -21.125mm | Bottom | 0mm | Surface mount
NetQ501_3 | Free-3 | -50.75mm | -11.85mm | Bottom | 0mm | Surface mount
NetC402_1 | Free-3 | -18.9mm | -19.65mm | Bottom | 0mm | Surface mount
NetC405_1 | Free-3 | -25.575mm | -14.1mm | Bottom | 0mm | Surface mount
NetQ400_6 | Free-3 | -4.1mm | -12.025mm | Bottom | 0mm | Surface mount
NetQ400_3 | Free-3 | -2.575mm | -6.55mm | Bottom | 0mm | Surface mount
NetR107_2 | Free-3 | -21.175mm | -14.55mm | Bottom | 0mm | Surface mount
NetQ800_3 | Free-3 | -43.225mm | -22.875mm | Bottom | 0mm | Surface mount
NetQ801_3 | Free-3 | -46.775mm | -22.875mm | Bottom | 0mm | Surface mount
NetQ802_3 | Free-3 | -50.325mm | -22.875mm | Bottom | 0mm | Surface mount
NetR105_2 | Free-3 | -14.15mm | -8.975mm | Bottom | 0mm | Surface mount
CM_PA01_GPIO | Via | -40.175mm | -26.675mm | Bottom | 0.25mm | Through hole
CM_PA00_GPIO | Via | -43.725mm | -26.675mm | Bottom | 0.25mm | Through hole
CM_PA17_SERCOM1_SCL | Via | -36.275mm | -24.95mm | Bottom | 0.25mm | Through hole
CM_PA16_SERCOM1_SDA | Via | -36.95mm | -23.775mm | Bottom | 0.25mm | Through hole
CM_PA24_SERCOM3_PAD2_SPI_MISO | Via | -20.225mm | -32.7mm | Bottom | 0.25mm | Through hole
CM_PA25_SPI_SS | Via | -22.55mm | -31.6mm | Bottom | 0.25mm | Through hole
CM_RESET_N | Via | -25.75mm | -32.175mm | Bottom | 0.25mm | Through hole
CM_PA23_SERCOM3_PAD1_SPI_SCK | Via | -22.125mm | -33.4mm | Bottom | 0.25mm | Through hole
CM_PA22_SERCOM3_PAD0_SPI_MOSI | Via | -20.35mm | -34.05mm | Bottom | 0.25mm | Through hole
CM_PA14_GCLK0 | Via | -21.35mm | -35.05mm | Bottom | 0.25mm | Through hole
CM_PA05_AIN5 | Via | -52.85mm | -28.725mm | Bottom | 0.25mm | Through hole
CM_PA11_GCLK5 | Via | -29.625mm | -25.325mm | Bottom | 0.25mm | Through hole
VCC_VSW | Via | -29.075mm | -49.725mm | Bottom | 0.25mm | Through hole
VCC_MCU_VDDCORE | Via | -27.35mm | -49.775mm | Bottom | 0.25mm | Through hole
STATUS_LED_CTRL | Via | -2.7mm | -12.25mm | Bottom | 0.25mm | Through hole
TARGET_USB_ID | Via | -32.275mm | -15.2mm | Bottom | 0.25mm | Through hole
CM_PA31_SWDIO | Via | -24.675mm | -35.675mm | Bottom | 0.25mm | Through hole
CM_PA30_SWCLK | Via | -25.9mm | -35.125mm | Bottom | 0.25mm | Through hole
TARGET_MCU_RESET | Via | -28.9125mm | -27.525mm | Bottom | 0.25mm | Through hole
NetCS300_1 | Via | -48.75mm | -80.075mm | Bottom | 0.25mm | Through hole
VCC_MCU_VDDANA | Via | -40.725mm | -57.95mm | Bottom | 0.25mm | Through hole
INPUT_VOLTAGE_DETECTED | Via | -9.925mm | -9.2mm | Bottom | 0.25mm | Through hole
VCC_TARGET_USB_P5V0 | Via | -22.525mm | -11.4mm | Bottom | 0.25mm | Through hole
NetD301_2 | Via | -36.625mm | -11.45mm | Bottom | 0.25mm | Through hole
CM_PA10_GPIO | Via | -52.7mm | -32.65mm | Bottom | 0.25mm | Through hole
CM_PA18_CMP0 | Via | -44.2mm | -20.225mm | Bottom | 0.25mm | Through hole
NetQ502_3 | Via | -50.75mm | -14.3mm | Bottom | 0.25mm | Through hole
DGI_GPIO3 | Via | -15.6mm | -26.2mm | Bottom | 0.25mm | Through hole
EDBG_CDC_USART_TX | Via | -27.575mm | -26.175mm | Bottom | 0.25mm | Through hole
DGI_GPIO2 | Via | -16.875mm | -26.2mm | Bottom | 0.25mm | Through hole
DGI_GPIO1 | Via | -18.15mm | -26.2mm | Bottom | 0.25mm | Through hole
DGI_GPIO0 | Via | -19.425mm | -26.2mm | Bottom | 0.25mm | Through hole
NetD401_1 | Via | -1.3mm | -7.25mm | Bottom | 0.25mm | Through hole
POWER_LED_CTRL | Via | -6.35mm | -8.75mm | Bottom | 0.25mm | Through hole
NetD400_1 | Via | -6.35mm | -10.05mm | Bottom | 0.25mm | Through hole
NetC404_1 | Via | -29.85mm | -20.25mm | Bottom | 0.25mm | Through hole
NetC407_1 | Via | -13.275mm | -7.4mm | Bottom | 0.25mm | Through hole
CM_PA09_AIN17 | Via | -38.75mm | -22.7mm | Bottom | 0.25mm | Through hole

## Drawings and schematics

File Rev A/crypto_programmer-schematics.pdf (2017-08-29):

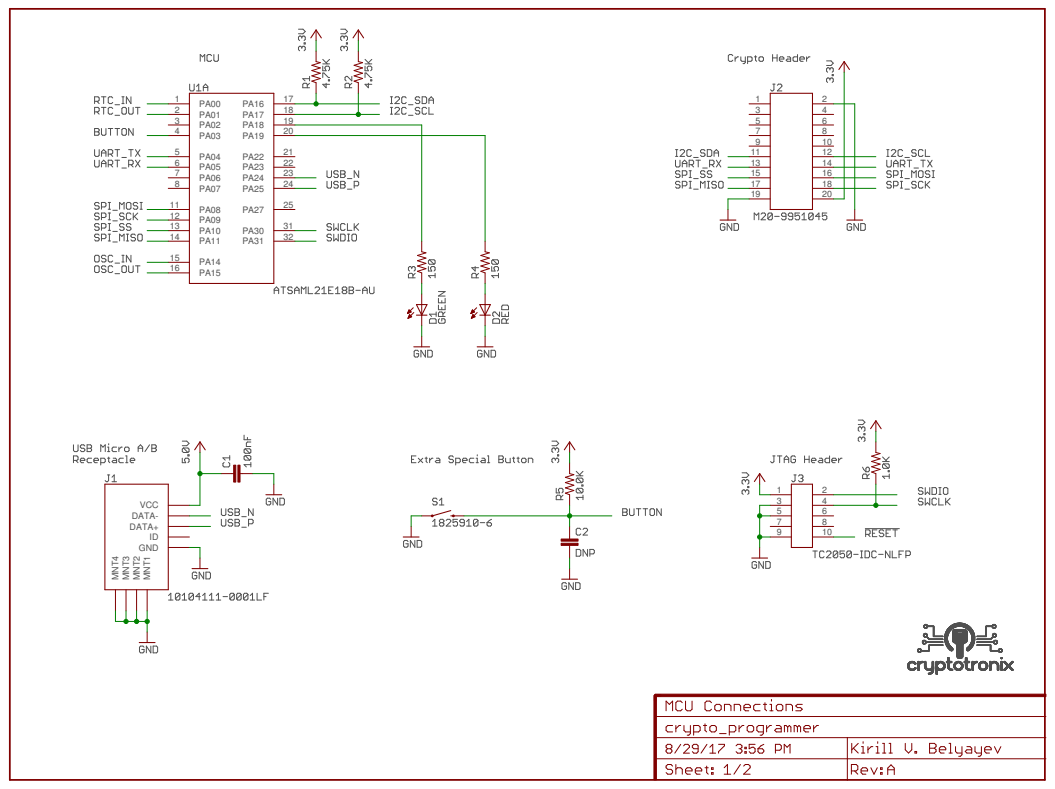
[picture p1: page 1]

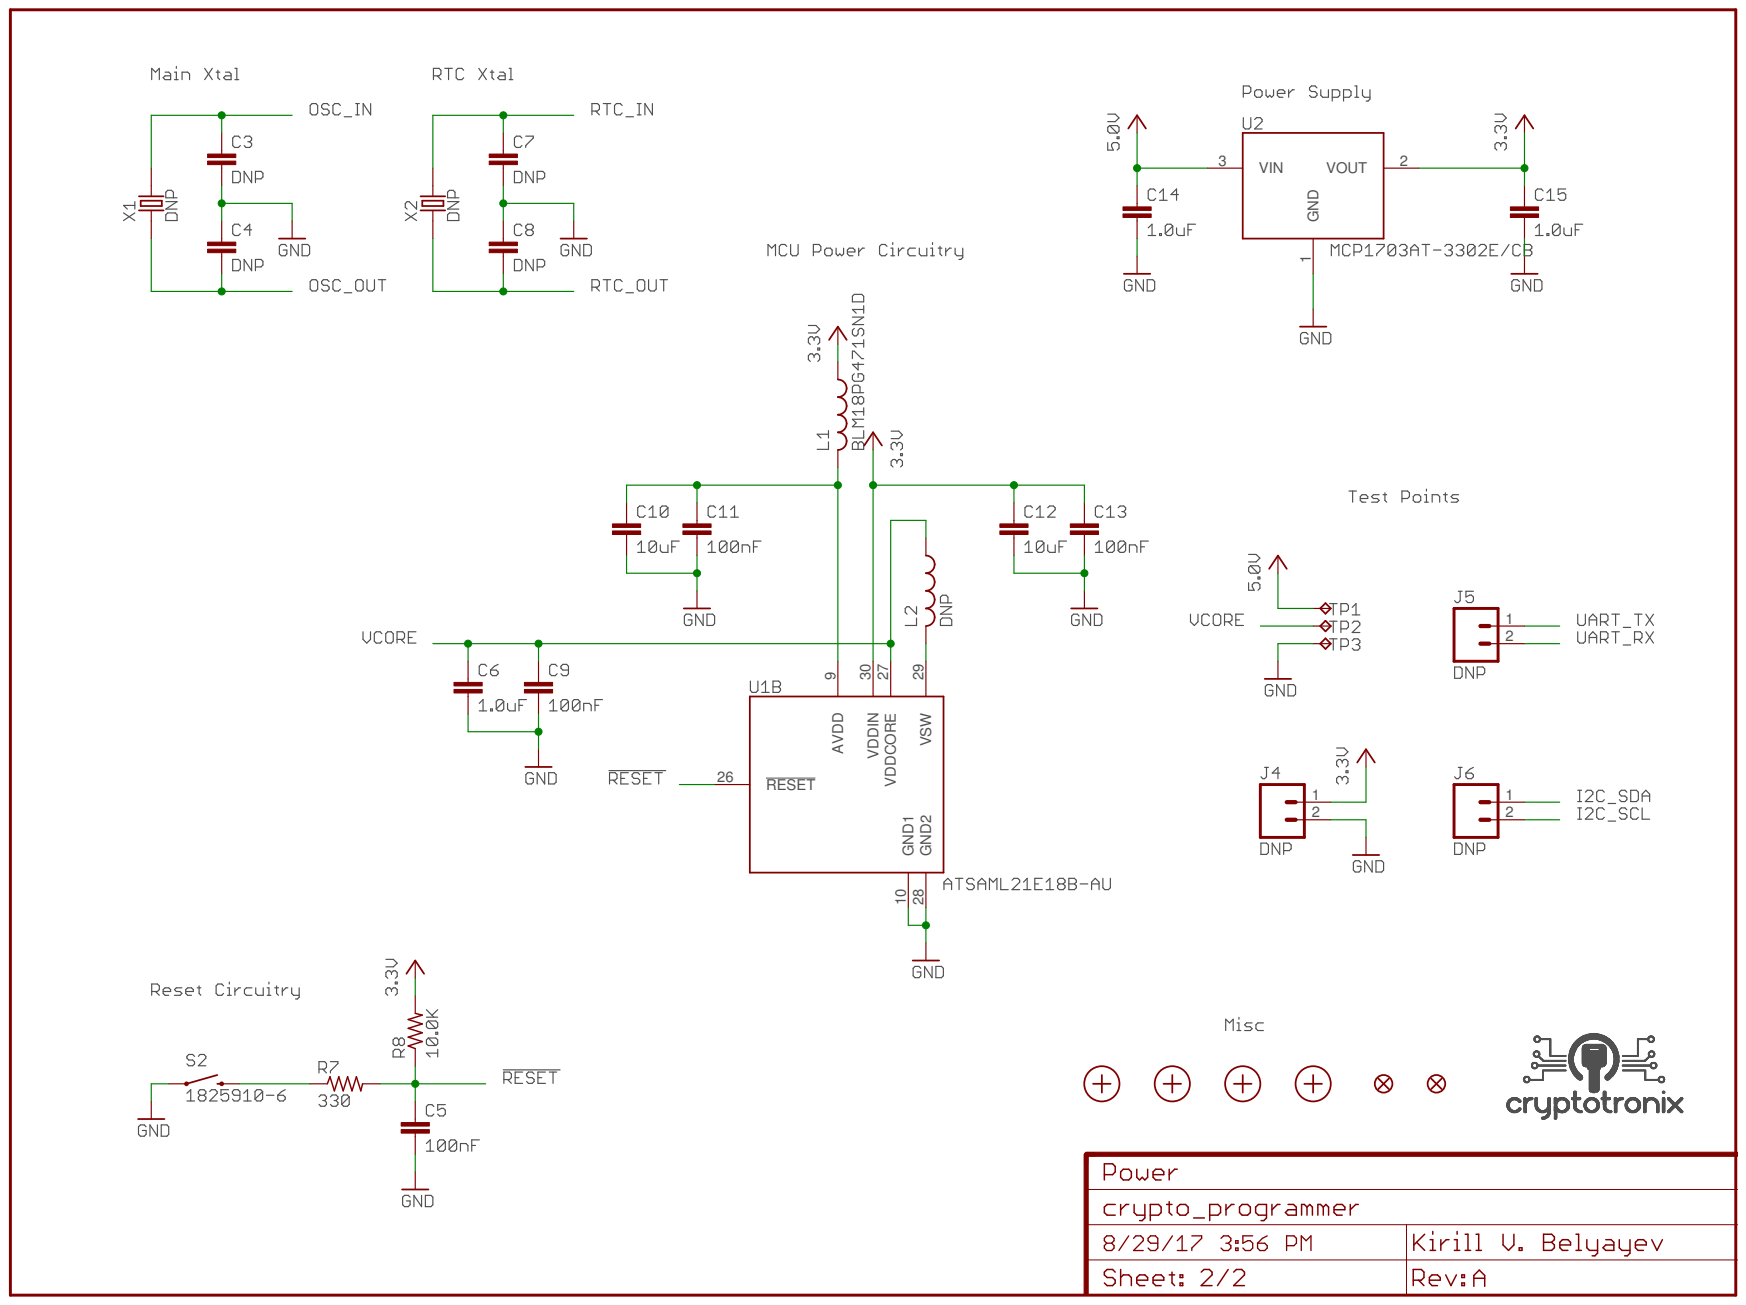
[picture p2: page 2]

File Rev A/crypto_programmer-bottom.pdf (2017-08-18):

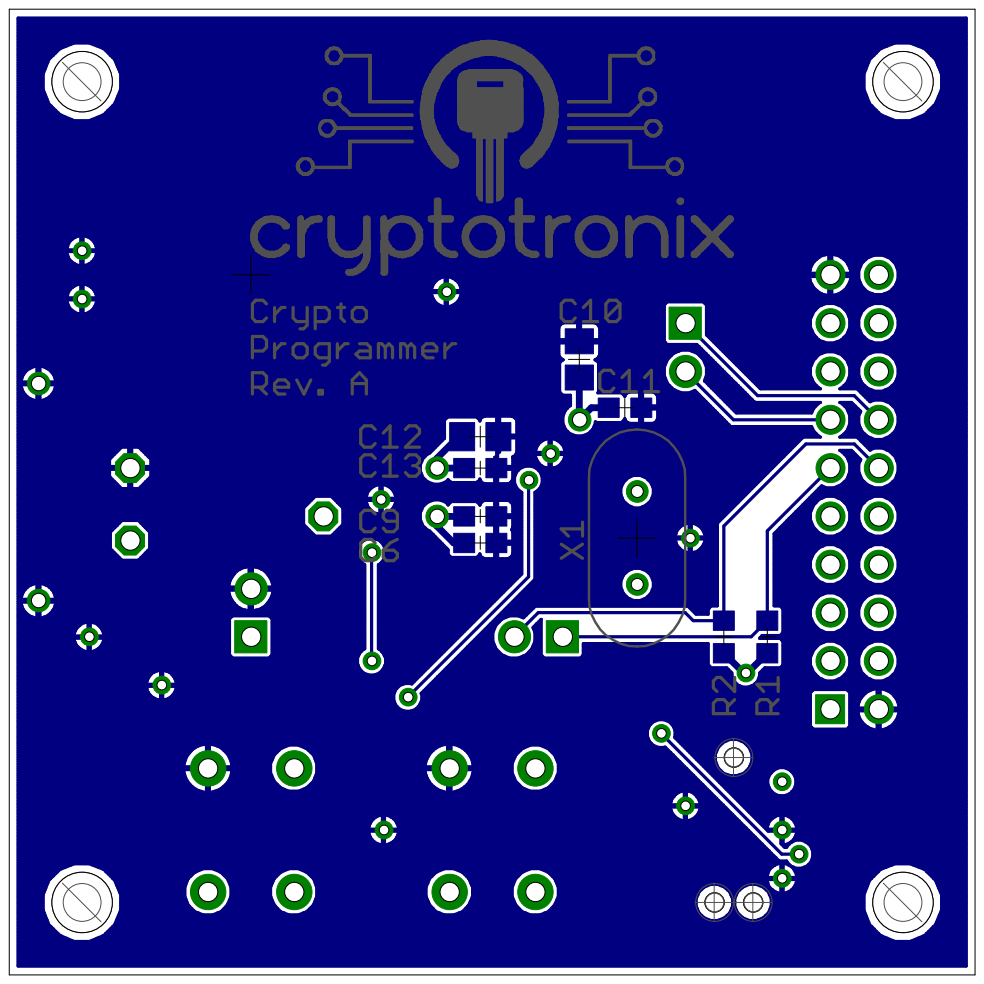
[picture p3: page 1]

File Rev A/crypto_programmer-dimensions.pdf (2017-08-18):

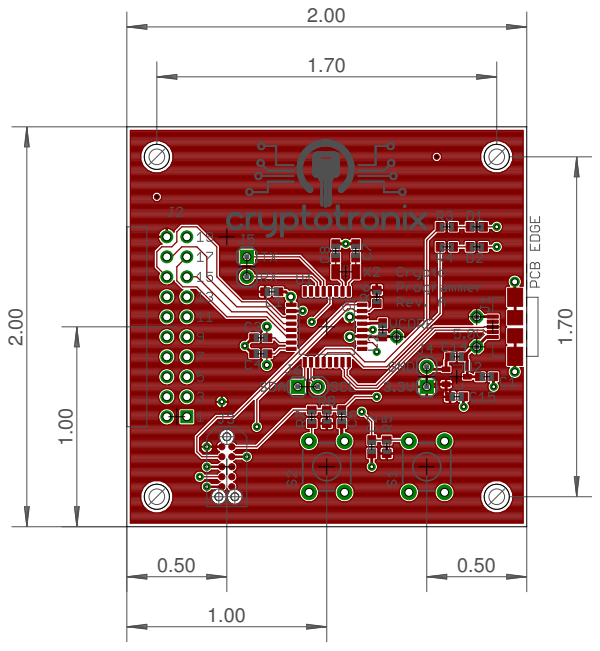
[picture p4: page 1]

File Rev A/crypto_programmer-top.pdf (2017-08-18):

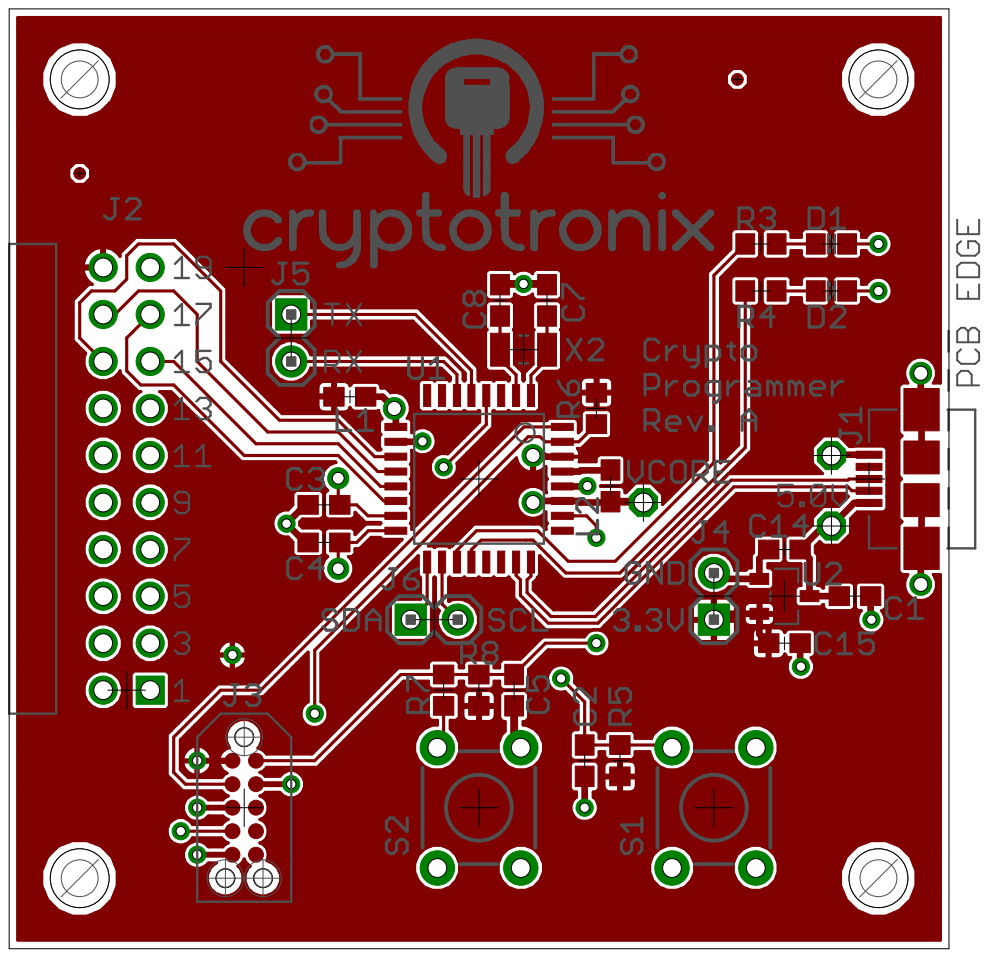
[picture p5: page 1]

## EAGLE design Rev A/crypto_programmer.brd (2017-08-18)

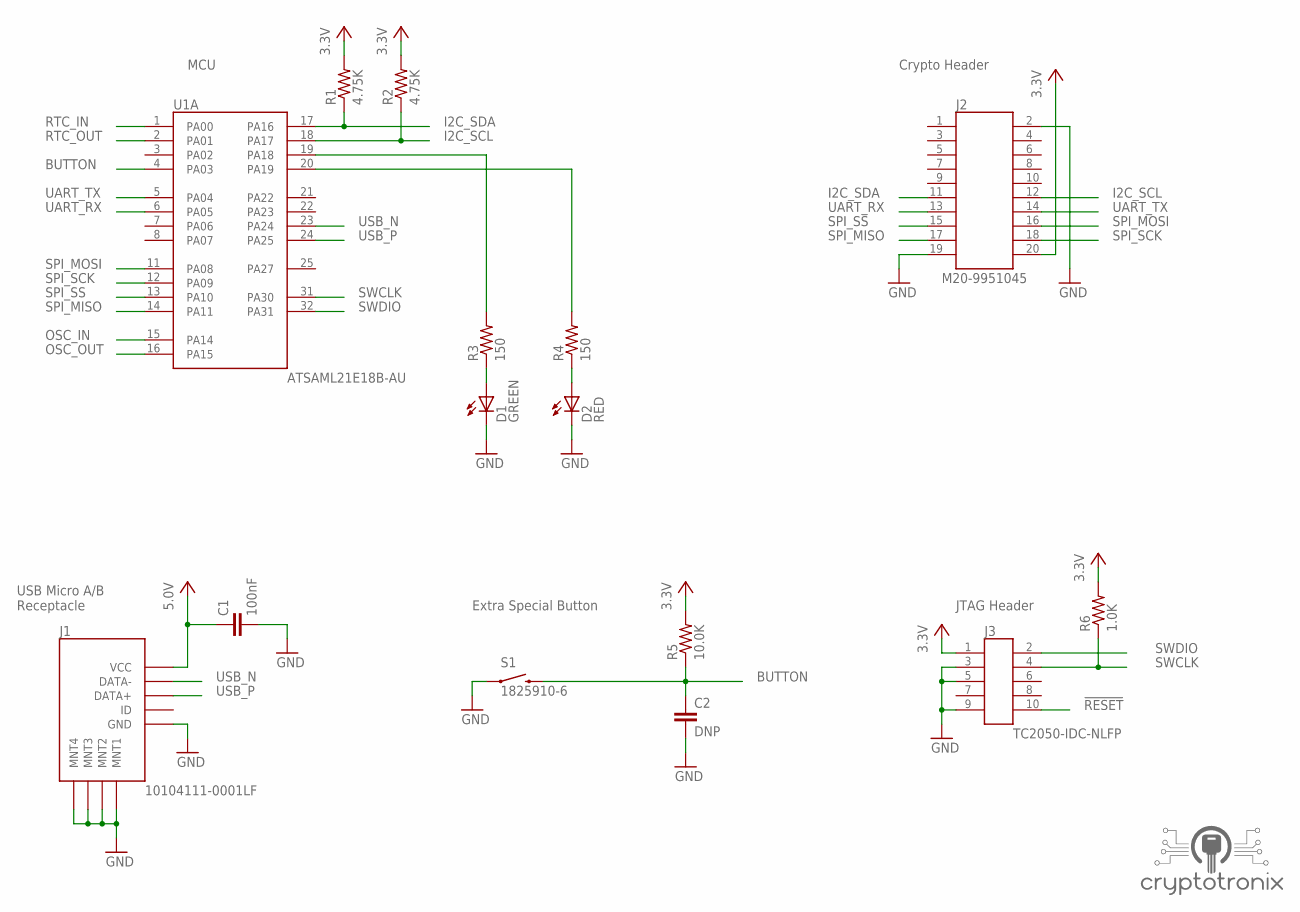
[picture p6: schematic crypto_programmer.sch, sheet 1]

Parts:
C1: 100nF; C0603
C2: DNP; C0603
D1: GREEN; 0603
D2: RED; 0603
J1: 10104111-0001LF
J2: M20-9951045
J3: TC2050-IDC-NLFP
LOGO1: CRYPTOTRONIX_LOGO
R1, R2: 4.75K; R0603
R3, R4: 150; R0603
R5: 10.0K; R0603
R6: 1.0K; R0603
S1: 1825910-6; SWITCH-TACT-TH
U1: ATSAML21E18B-AU; ATSAML21E18-AU

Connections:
0V: C1.2, C2.2, D1.C, D2.C, J1.P$5 (GND), J1.P$6 (MNT1), J1.P$7 (MNT2), J1.P$8 (MNT3), J1.P$9 (MNT4), J2.2, J2.19, J3.3, J3.5, J3.9, S1.1; also elsewhere on the board
3.3V: J2.20, J3.1, R1.2, R2.2, R5.2, R6.2; also elsewhere on the board
5.0V: C1.1, J1.P$1 (VCC); also elsewhere on the board
!RESET: J3.10; also elsewhere on the board
BUTTON: C2.1, R5.1, S1.3 (2), U1.4 (PA03)
I2C_SCL: J2.12, R2.1, U1.18 (PA17); also elsewhere on the board
I2C_SDA: J2.11, R1.1, U1.17 (PA16); also elsewhere on the board
unnamed: R4.2, U1.20 (PA19)
unnamed: D2.A, R4.1
unnamed: D1.A, R3.1
unnamed: R3.2, U1.19 (PA18)
OSC_IN: U1.15 (PA14); also elsewhere on the board
OSC_OUT: U1.16 (PA15); also elsewhere on the board
RTC_IN: U1.1 (PA00); also elsewhere on the board
RTC_OUT: U1.2 (PA01); also elsewhere on the board
SPI_MISO: J2.17, U1.14 (PA11)
SPI_MOSI: J2.16, U1.11 (PA08)
SPI_SCK: J2.18, U1.12 (PA09)
SPI_SS: J2.15, U1.13 (PA10)
SWCLK: J3.4, R6.1, U1.31 (PA30)
SWDIO: J3.2, U1.32 (PA31)
UART_RX: J2.13, U1.6 (PA05); also elsewhere on the board
UART_TX: J2.14, U1.5 (PA04); also elsewhere on the board
USB_N: J1.P$2 (DATA-), U1.23 (PA24)
USB_P: J1.P$3 (DATA+), U1.24 (PA25)

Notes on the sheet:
MCU
JTAG Header
Extra Special Button
Crypto Header
USB Micro A/B Receptacle

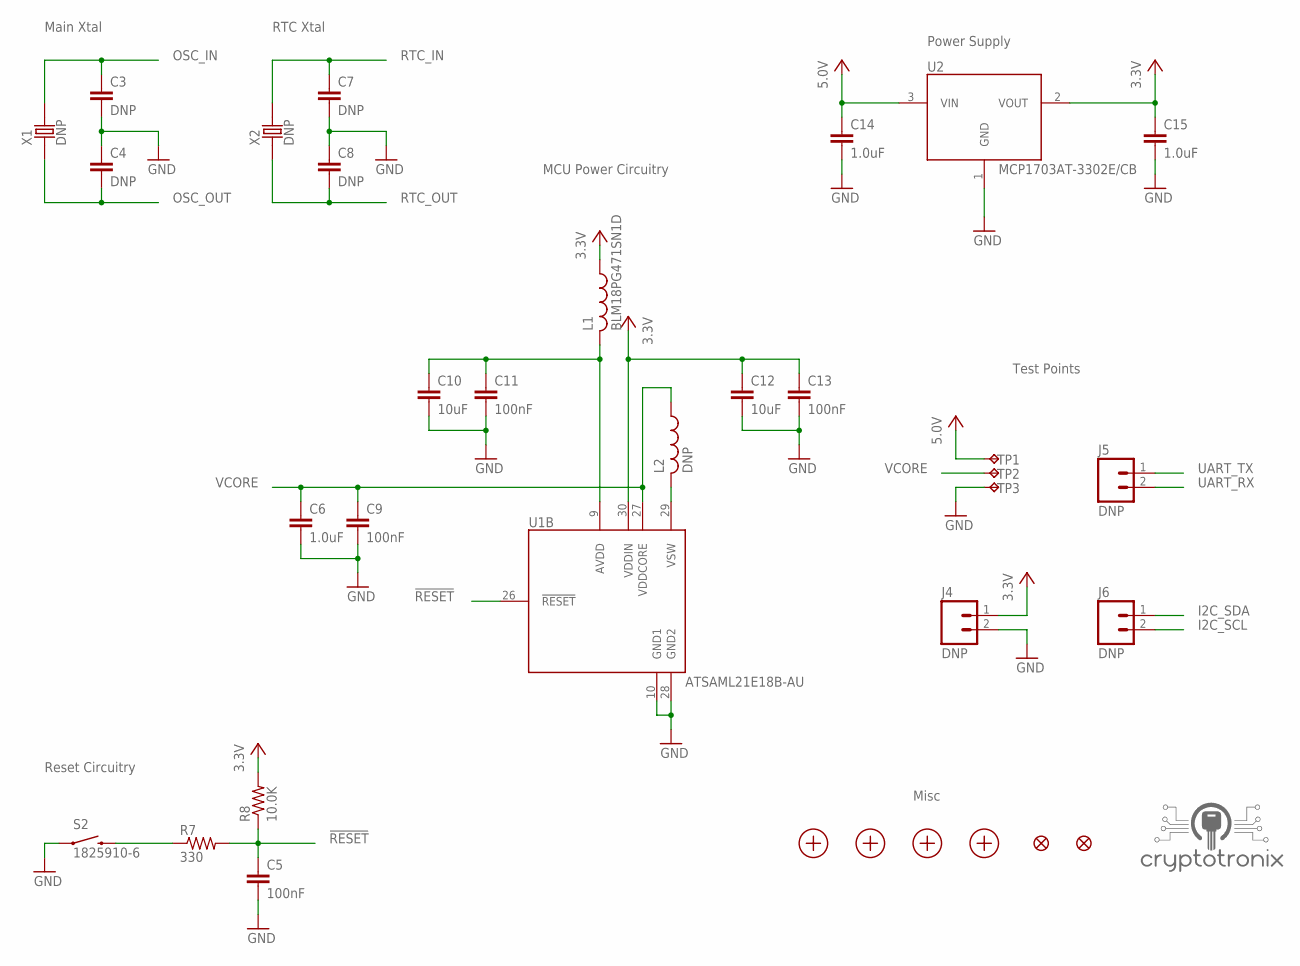
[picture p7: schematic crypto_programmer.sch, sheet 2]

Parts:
C3, C4, C7, C8: DNP; C0603
C5, C9, C11, C13: 100nF; C0603
C6, C14, C15: 1.0uF; C0603
C10, C12: 10uF; C0805
FD1, FD2: FIDUCIALUFIDUCIAL; MICRO-FIDUCIAL
J4, J5, J6: DNP; M20-9990246
L1: BLM18PG471SN1D; L0603
L2: DNP; L0603
LOGO2: CRYPTOTRONIX_LOGO
MNT1, MNT2, MNT3, MNT4: MOUNT-HOLE-NO-PLATE4-40; MOUNT-HOLE-NO-PLATE-4-40
R7: 330; R0603
R8: 10.0K; R0603
S2: 1825910-6; SWITCH-TACT-TH
TP1, TP2, TP3: TEST-POINT40MIL; TEST-POINT-40MILL
U1: ATSAML21E18B-AU; ATSAML21E18-AU
U2: MCP1703AT-3302E/CB
X1: DNP; ABL-8.000MHZ-B2
X2: DNP; ABS07AIG-32.768KHZ-9-T

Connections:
0V: C3.2, C4.1, C5.2, C6.2, C7.2, C8.1, C9.2, C10.2, C11.2, C12.2, C13.2, C14.2, C15.2, J4.2, S2.1, TP3.1, U1.10 (GND1), U1.28 (GND2), U2.1 (GND); also elsewhere on the board
3.3V: C12.1, C13.1, C15.1, J4.1, L1.1, R8.2, U1.30 (VDDIN), U2.2 (VOUT); also elsewhere on the board
5.0V: C14.1, TP1.1, U2.3 (VIN); also elsewhere on the board
!RESET: C5.1, R7.2, R8.1, U1.26 (!RESET); also elsewhere on the board
I2C_SCL: J6.2; also elsewhere on the board
I2C_SDA: J6.1; also elsewhere on the board
unnamed: L2.2, U1.29 (VSW)
unnamed: C10.1, C11.1, L1.2, U1.9 (AVDD)
unnamed: R7.1, S2.3 (2)
OSC_IN: C3.1, X1.2; also elsewhere on the board
OSC_OUT: C4.2, X1.1; also elsewhere on the board
RTC_IN: C7.1, X2.2; also elsewhere on the board
RTC_OUT: C8.2, X2.1; also elsewhere on the board
UART_RX: J5.2; also elsewhere on the board
UART_TX: J5.1; also elsewhere on the board
VCORE: C6.1, C9.1, L2.1, TP2.1, U1.27 (VDDCORE)

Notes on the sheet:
MCU Power Circuitry
Reset Circuitry
Test Points
Main Xtal
RTC Xtal
Power Supply
Misc

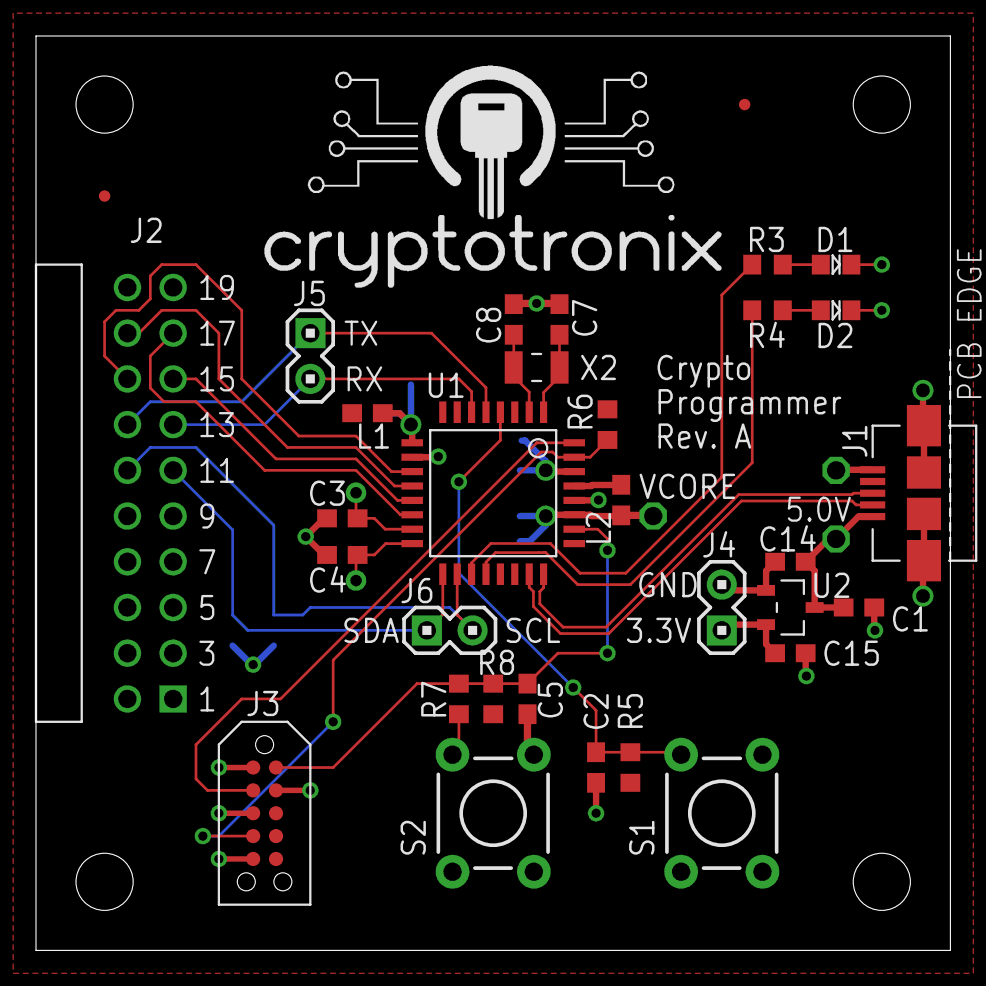
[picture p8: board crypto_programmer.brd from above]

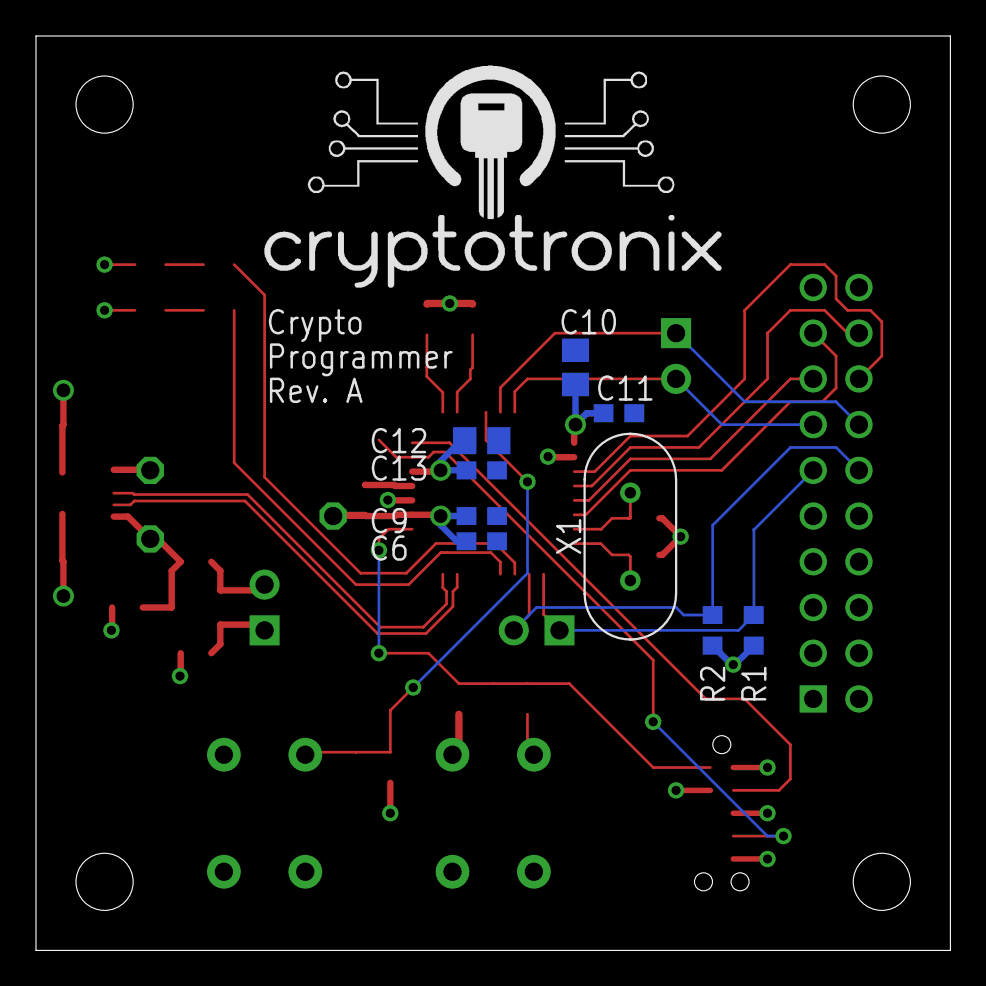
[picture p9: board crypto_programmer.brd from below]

Board: 2 copper layers, 50.8 x 50.8 mm, 50 parts (10 on the bottom side), 29 nets.

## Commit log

2017-08-18 Inital commit cont...
    [Assembly Testpoint Report for SAML21_Xplained_Pro_release_rev4.csv, Bill of Materials Print- SAML21_Xplained_Pro_release_rev4.xls, SAML21_Xplained_Pro.PrjPCB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]
2017-08-18 Adding BOM
    [crypto_programmer.brd, crypto_programmer.sch]
2017-08-18 Updating BOM 2
    [crypto_programmer.brd, crypto_programmer.sch]
2017-08-29 Updating schematics pdf
